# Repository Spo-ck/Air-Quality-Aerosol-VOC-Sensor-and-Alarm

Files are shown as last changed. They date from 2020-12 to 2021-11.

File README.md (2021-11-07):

# Air Quality & Aerosol (VOC) Sensor and Alarm

During the COVID-19 Pandemic, monitoring the Air Quality is important. Because of this, I developed this compact Air Quality Monitor based on the M5StickC Microcontroller and the SGP30 Sensor. The System is very small and can also be worn as a smart watch. When the eCO2  hits the threshold of 1000 ppm or the TVOC hit the threshold of 150 ppb, the sensor will trigger an alarm (sound and lght), so that you can leave a dangerous and potentially infectious room or open the windows.

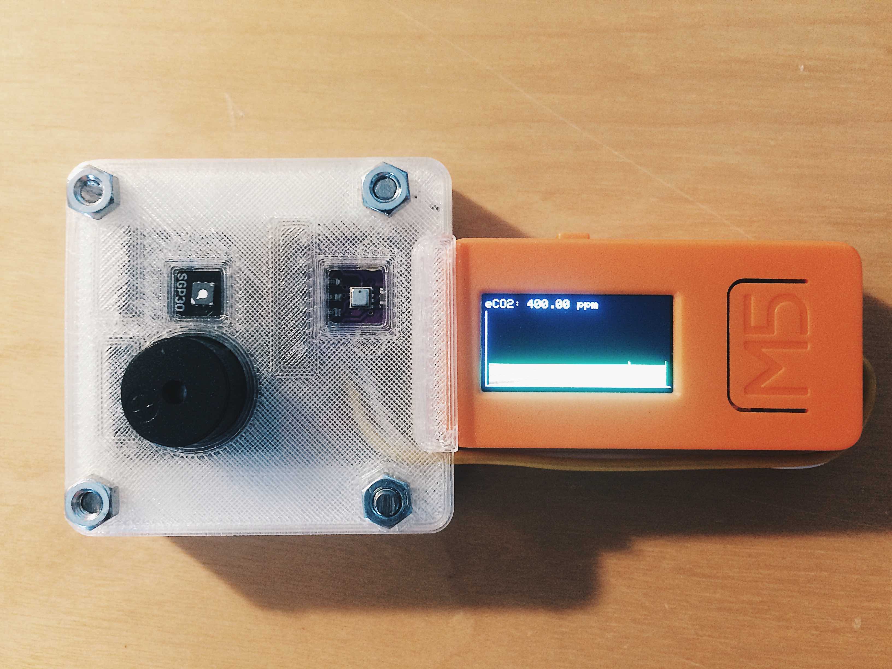
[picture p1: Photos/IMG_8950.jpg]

***System Chart View***

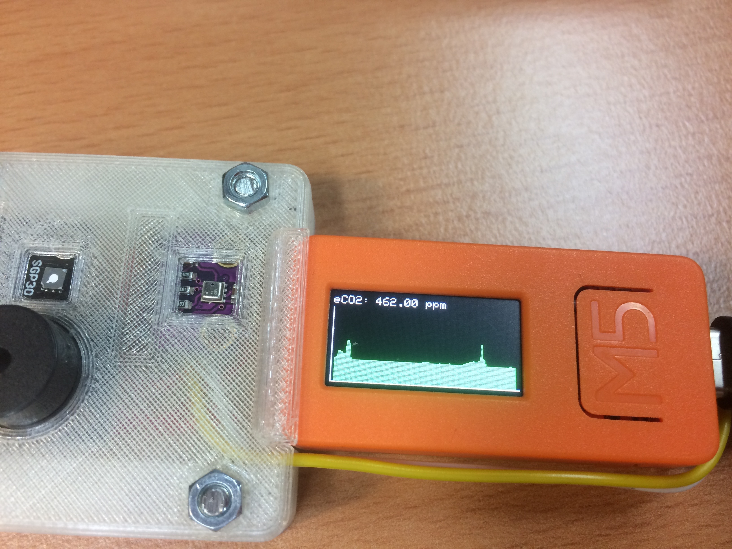
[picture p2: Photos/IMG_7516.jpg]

***System Chart View***

## Electronic

### Part List

#### Electronic
* [Buzzer module](https://www.makershop.de/module/audio/passiver-buzzer-summer/)
* [BME280 Barometric Sensor](https://www.makershop.de/sensoren/temperatur/bme280/)
* [GY-SGP30 Gas Sensor (alternative Grove SGP30)](https://www.ebay.de/itm/GY-SGP30-Air-Quality-Sensor-Breakout-VOC-and-eCO2-QITA/353147995118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)
* [M5StickC Microcontroller](https://eckstein-shop.de/M5Stack-M5StickC-PLUS-ESP32-PICO-Mini-IoT-Development-Kit)
* [Grove Sensor Cable](https://eckstein-shop.de/M5Stack-Buckled-Grove-Cable-20cm-5pcs)
* [PCB](https://www.reichelt.de/punkt-streifenrasterplati-hartpapier-160x100mm-h25ps160-p23953.html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)
* [Generic 1x8 Pin Header 2,54mm](https://www.conrad.de/de/p/wws-40-g-sl40g1-pin-header-1x40-rm2-54-straight-au-inhalt-20-stueck-800166396.html)
* Generic solid core wires (PCB)
* Generic Lead Solder

#### Tools
* [Soldering Station](https://www.conrad.de/de/p/basetech-zd-931-loetstation-digital-48-w-150-bis-450-c-1460697.html)
* [Solder Pump](https://www.conrad.de/de/p/toolcraft-lee-192-entloetsaugpumpe-antistatisch-2196503.html)
* [Third Hand](https://www.conrad.de/de/p/inline-dritte-hand-mit-lupe-800404647.html)
* [Soldering Tools](https://www.conrad.de/de/p/toolcraft-lns-151-platinenbesteck-6teilig-2182257.html)

### Pin Mapping
* GND:  Buzzer Module -, BME280 GND, SGP30 GND
* 3.3V: Buzzer Module +, BME280 VIN, SGP30 VIN
* G26:  Buzzer Module S
* G32:  BME280 SDA, SGP30 SDA
* G33:  BME280 SCL, SGP30 SCL

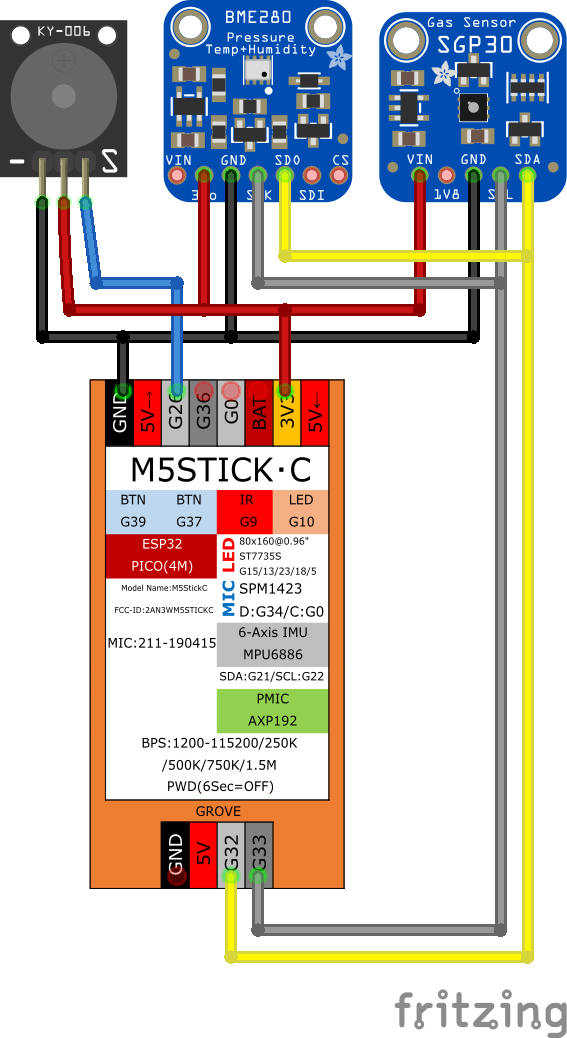
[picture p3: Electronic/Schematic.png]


***Electronic Schematic***

### Assembly

The system basically consists out of the M5StickC Microcontroller, a Buzzer Module, a BME280 Barometric Sensor Module (Temperature, Humidity, Pressure) and an SGP30 Gas Sensor Module (eCO2, TVOC, Ethanol, H2). The Buzzer Module is connected to the M5StickCs Pin Header, and the seonsors are connected to the I2C bus via the Grove connector.
All 3 components are soldered together on a single prototyping PCB. To this prototyping PCB is then soldered a 1x8 Pin Header (2.54mm) so that the PCB can be connected to the front pin header of the M5StickC. As power supply off all 3 modules, the 3.3V and the GND Pin of the M5StickCs Pin Header are utilized. The Buzzer-Modules signal pin is soldered to Pin 26, because this pin allows output signals. 
Because of the sensor modules need to be connected to the I2C Bus, which is only available on the Grove connector of the M5StickC, a 20cm Grove sensor cable was utilized. One connector was cutted of, and the 5V and GND Cables were removed. The remaining Yeallow (G32, SDA) and white (G33, SCL) cables were soldered to the corresponding pins on the PCD, to connect them to the sensor module

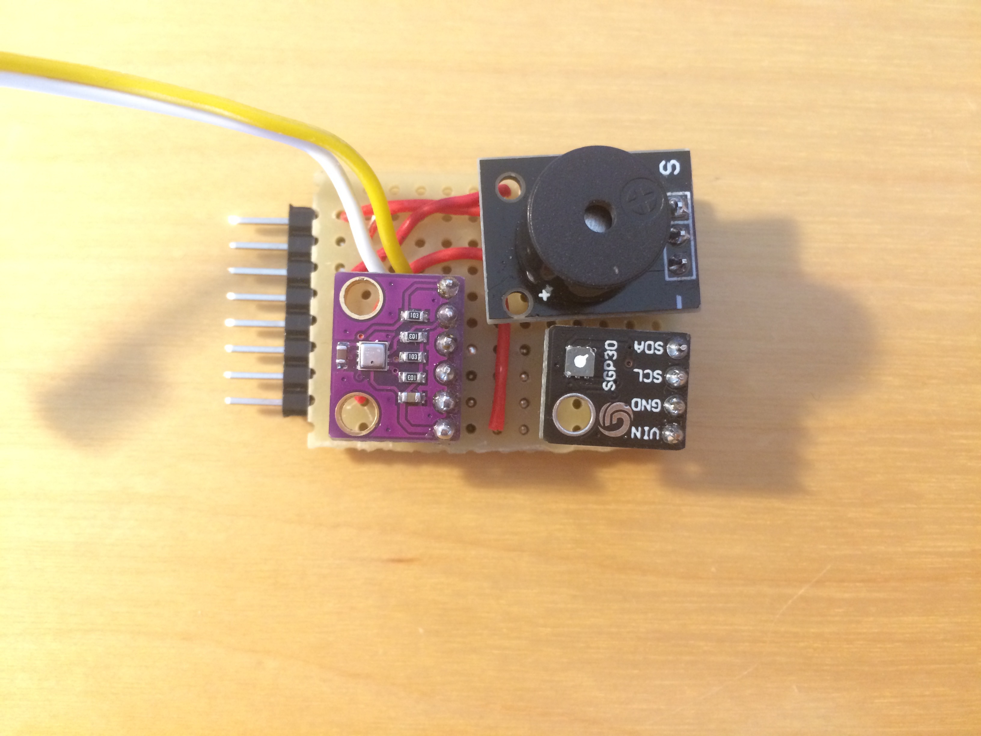
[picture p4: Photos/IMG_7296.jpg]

***PCB Front***

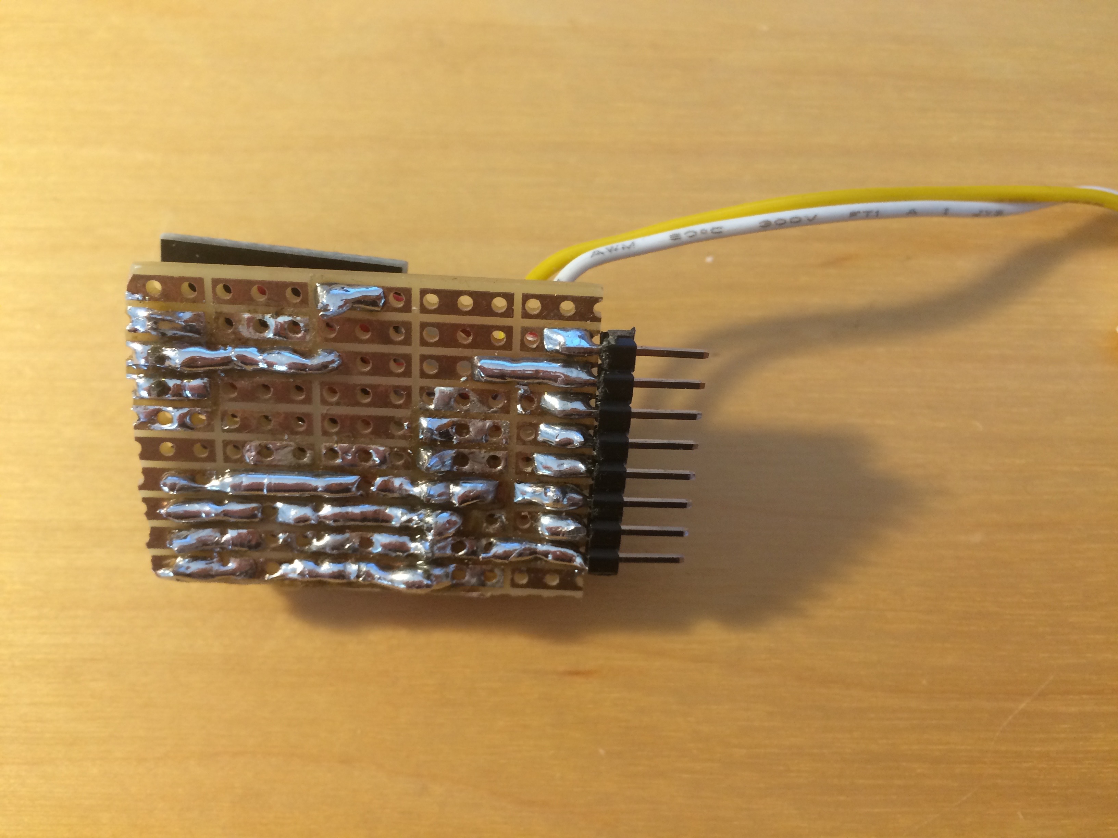
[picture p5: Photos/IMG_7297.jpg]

***PCB Back***

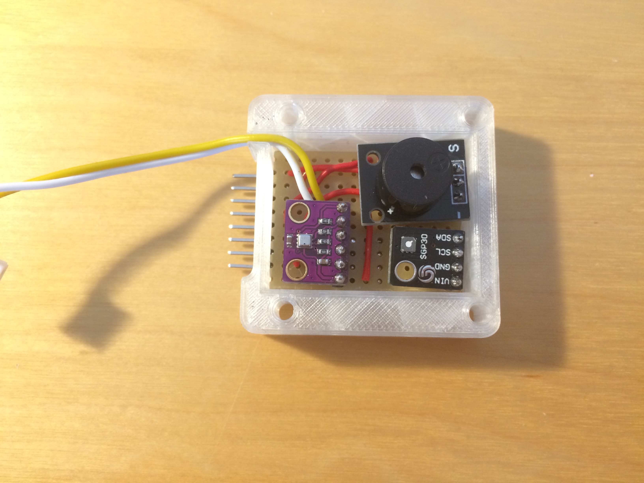
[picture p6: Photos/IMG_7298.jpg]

***PCB Cased***

## 3D-Printing

### Settings

* Profile:  0.2mm
* Infill:   10%
* Support:  Yes

### Parts
* Filament: PLA ([OWL-Filament](https://owl-filament.de))
* Printer:  Creality Ender 3
* Generic M3 Screws

### Assembly

The Sensor PCB Case consists out of 3 parts, a body frame, a front and a bottom part. For the Assembly, the Soldered PCB is first fittet into the Body Frame from the bottom so that the case mathes the pin header exactly. The Sensor cable is the placed into the small hole on the top side of the frame. After that, the Front and Bottom Party are crewed to the case. The Screwd sensor case it then first plugged into the Pin Header of the M5StickC. After that, the Sensor Cable is plugged into the Grove Connecter.


***PCB Cased***

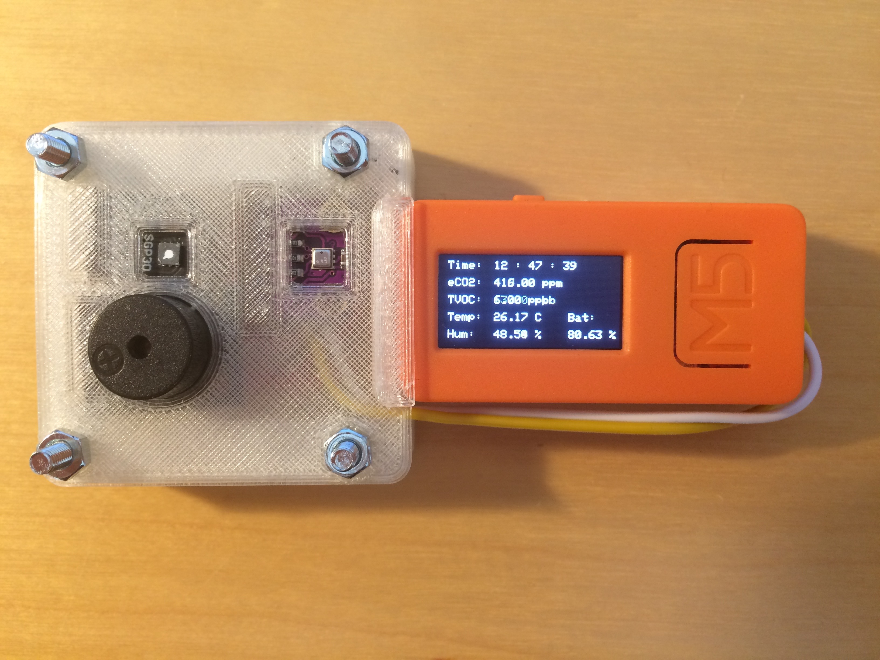
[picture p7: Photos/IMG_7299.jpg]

***System Detailed View***

## Arduino Code

### Libraries

* [M5StickC](https://github.com/m5stack/M5StickC)
* Wire.h
* [Adafruit_Sensor.h](https://github.com/adafruit/Adafruit_Sensor)
* [Adafruit_SGP30.h](https://github.com/adafruit/Adafruit_SGP30)
* [Adafruit_BME280.h](https://github.com/adafruit/Adafruit_BME280_Library)
* EEPROM.h

### About the Code

M5STcikC

The purpose of this Microcontroller Code is to generate sensor data from the sensors connected to trigger an Alarm when the Air Quality is bad. For this reason, the SGP30 Sensor Module measures eCO2 and TVOC in the breathing Air. The BME280 Barometric Sensor is required to calibrate the SGP30, and therefore to enhance its accuracy.
When the eCO2 value is over 1000 ppm, or the TVOC value is over 150 ppb, an alarm is triggered. The alarm will result in an alarm sound provided by the buzzer modele, the built in LED enlight in RED and the display turning RED. By the built in settings options, the Buzzer can also set into silent mode, where only the LED and the Display are tiggered in case of an alarm. The alarm sound is only triggered once in 60s, when the eCO2 or TVOC value hits the threshold value, but the LED will be enlighted in RED untill the Sensor Value is below the threshold again. In addition, the buzzer then disabled for 1 minute. Because of this, you will not hear multible buzzer alarms, when the sensor value is falling below, and hitting the threshold again within one minute.

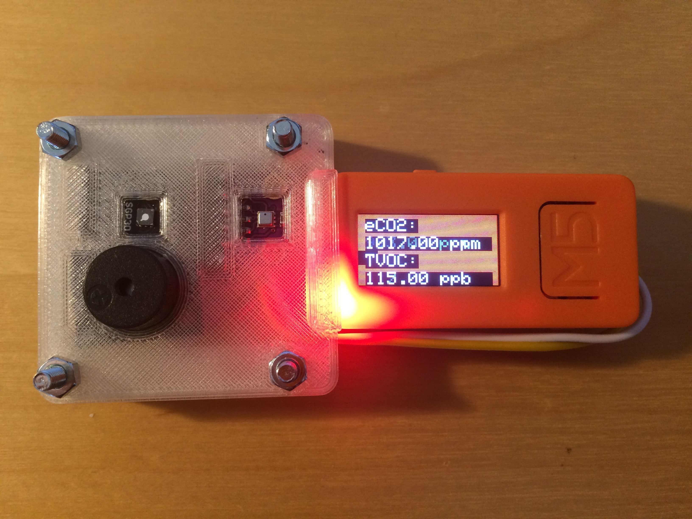
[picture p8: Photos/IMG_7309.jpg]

***System Alarm***

The System has three built in views. The Detailed View shows only the eCO2 and the TVOC values, whereas the Air Quality view shows the Time, Temperature, Humidity and the Battery Status in addition. More advanced is the Chart View, which shows the eCO2 value for the last 20min. If the critical threshold was hit, the bar shown will turn red, and if the value is below, the bar will be green. 
To navigate through the different views, the front button (Button A) is used. The last view is also stored in EEPROM, so that the sensor will start in the last used view when it starts next time.


***System Detailed View***

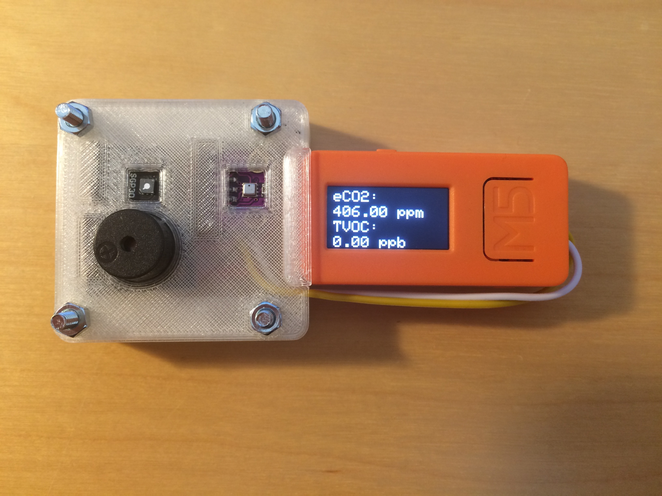
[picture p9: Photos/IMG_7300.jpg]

***System Air Quality View***

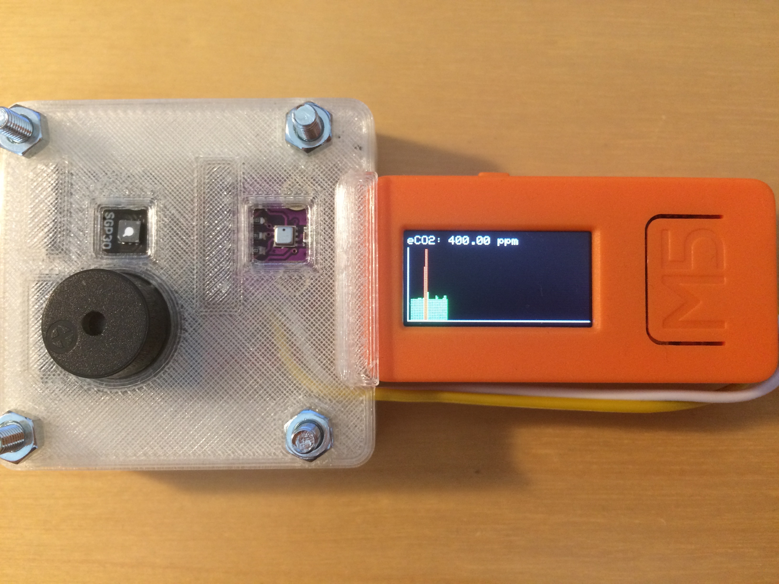
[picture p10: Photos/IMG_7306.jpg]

***System Chart View***

Nomally, the display is On all time, but it is also possible to disable the display. In this mode, the front button needs to be pressed one time to turn the display on for 5s. After that, pressing this button again will make the view change as usual.

In addidion, a settings view is implemented. In the settings view, one can change the Display Mode (Display always on or on for 5s) and the Alarm Mode (Buzzer turned off or on). This view is opened when the side button (Button B) is pressed. In this view, the first option it the Display Mode. When the Front Button is pressed, the Mode will change (Display always on or on for 5s). The option is confirmed with pressind the side button again. After that, the settings for the Alarm Mode (Buzzer turned off or on) is opened and can be changed with pressing the front button. In general, the active settings option is indicated with a red line on the left side. Pressing the side button a third time will confirm the settings, and open the last Sensor View again.

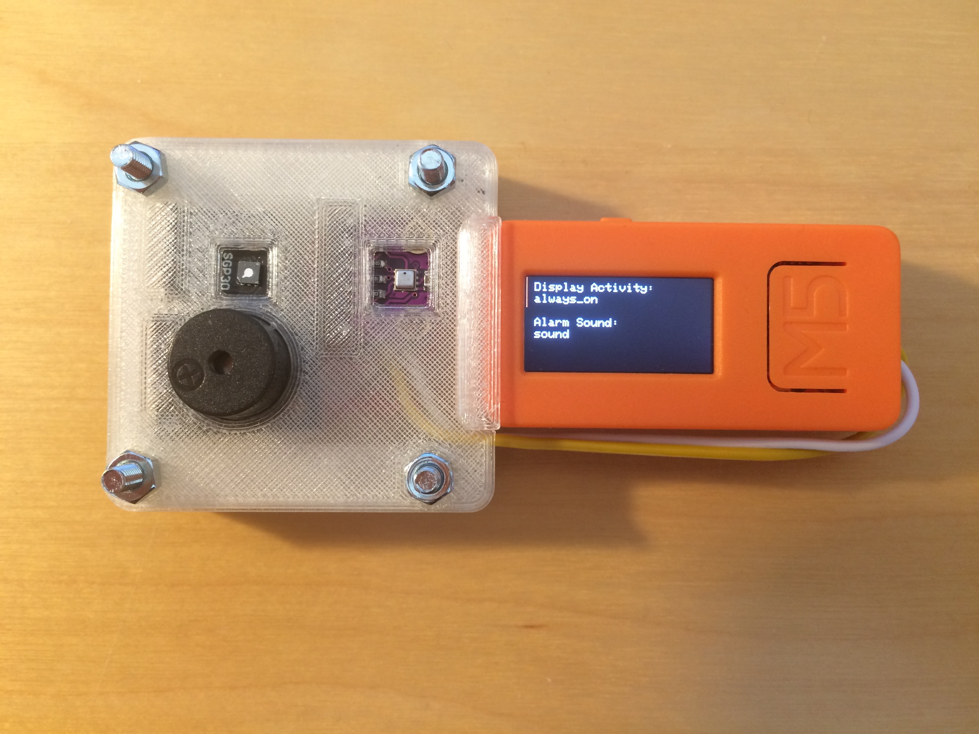
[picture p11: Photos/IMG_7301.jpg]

***System Settings***

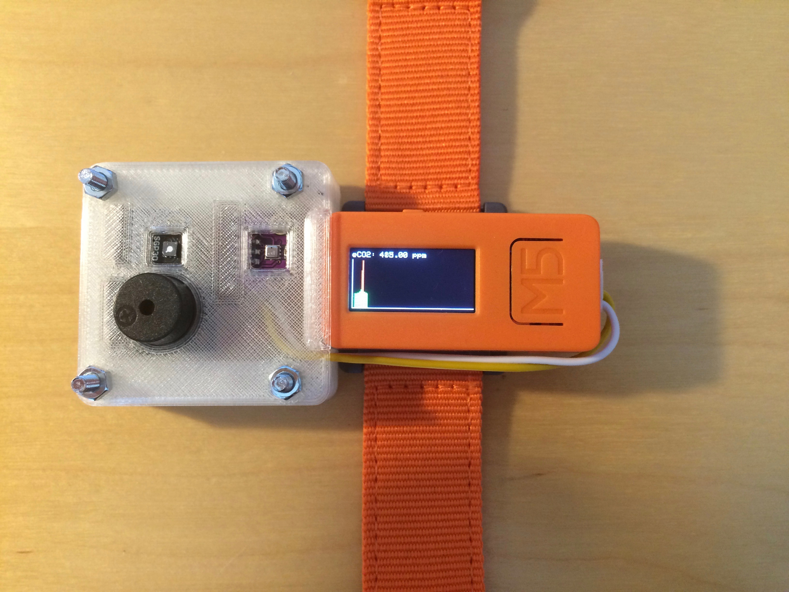
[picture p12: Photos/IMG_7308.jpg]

***System as Smart Watch close up***

### How To

In order to flash this code on the M5StickC, the Arduino IDE needs to download and to be installed first. Then, the M5StickCs driver and the above mentioned libraries need to be installed. You can then open (or copy/past) the code into the IDE and flash it.

* [M5StickC Manual and Software](https://m5stack.com/pages/download)
* [Arduino IDE](https://www.arduino.cc/en/software)

## Limit Values

In my design I used the value of 1000 ppm eCO2 and 150 ppb TVOC as limits for an alarm of the Sensor System. These limits mark the boundary condition for unobjectionable indoorair, between 1000 ppm and 2000ppm CO2 and between 150 ppb and 1300 ppb TVOC the airquality is questionable. Above these limits the Airquality is not directly infectious, but hygienically inacceptable. I got these values from the following sources:

* [Umweltbundesamt CO2 Grenzwerte in Innenräumen](https://www.umweltbundesamt.de/sites/default/files/medien/pdfs/kohlendioxid_2008.pdf)
* [Air-Q TVOC Limits](https://www.air-q.com/messwerte/voc)

## Datasheets

* [Sensurion SGP30 Gas Sensor](https://www.sensirion.com/fileadmin/user_upload/customers/sensirion/Dokumente/9_Gas_Sensors/Datasheets/Sensirion_Gas_Sensors_Datasheet_SGP30.pdf)
* [Bosh Sensortech BME280 Barometric Sensor](https://www.bosch-sensortec.com/media/boschsensortec/downloads/datasheets/bst-bme280-ds002.pdf)

## Hot Sensors

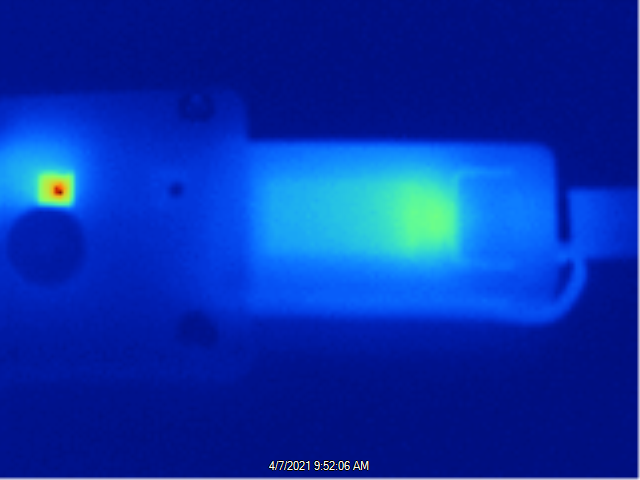
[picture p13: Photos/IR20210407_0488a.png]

***Thermal Scan***

Some users reported their SGP30 Sensor Boards where heating up, but during my testruns, I was not able to feel the heat. To clearify the issue, I did a thermal scan of my Sensor System. In general, the SGP30 sensor uses hot plates to measure TVOC and CO2 equivalents. Because of this, the Sensor gets hot in its centre spot, and also heats up its case. In my thermal scan, the sensors case (green) heated up to 43°C, and the central hot plate (red) heated up to 52°C. Since my sensor did not consume more current during my testruns then expected, since it was perfectly working with four sensor readings per second and because I was not able to sense this heat with my finger on the sensor, I would say it is save to use the sensor and reasonable that its getting hot.

## Still to be implemented

Every Gas Sensor is different, so it also needs to be calibrated. In order to calibrate it, it needs to be turned on for 12h, and this value is then valid for 7 days. To do so, the value needs to be stored in EEPROM, and send to the sensor in the Settings function. Because I never used it for 12h, this is not implemented yet. If not set, the sensor used 400 ppm for eCO2 and 0 ppb for TVOC as calibration value.
Also, it was not possible to set the display off completely. In the current implementation, it will only be black in the 5s-On mode and not completely off.

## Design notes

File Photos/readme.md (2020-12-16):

# Photos


***PCB Front***


***PCB Back***


***PCB Cased***


***System Detailed View***


***System Air Quality View***


***System Chart View***

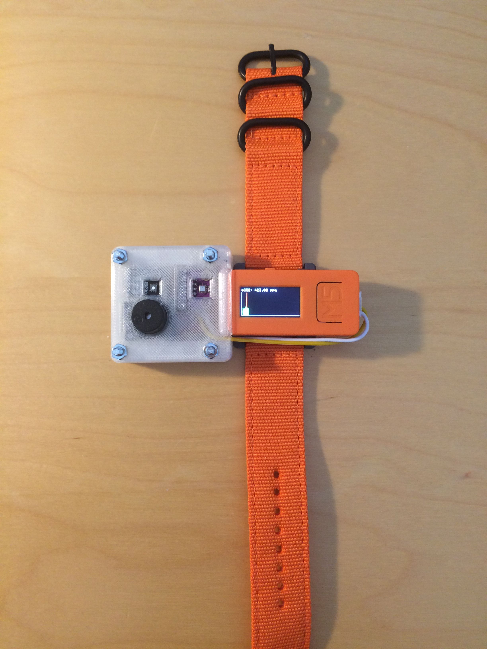
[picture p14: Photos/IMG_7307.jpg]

***System as Smart Watch***


***System as Smart Watch close up***


***System Alarm***


***System Settings***

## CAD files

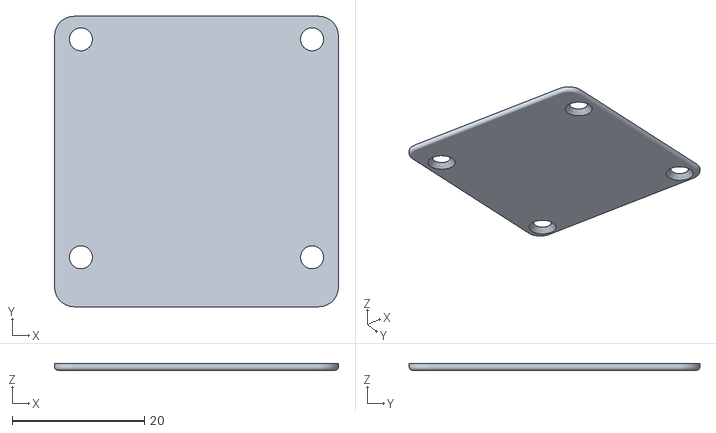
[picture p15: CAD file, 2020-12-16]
3d-Printing/AirQualitySensor07_bottom_plate.stl
43.0 x 44.0 x 1.00

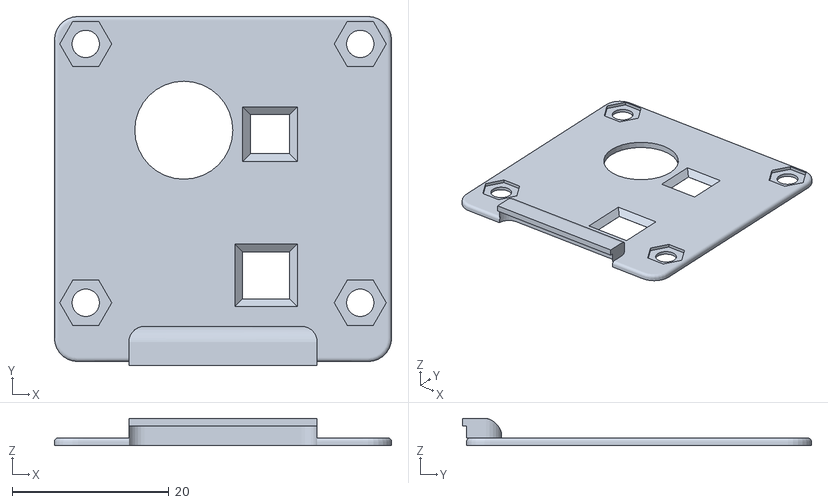
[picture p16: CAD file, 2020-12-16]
3d-Printing/AirQualitySensor08_top_plate.stl
43.0 x 44.5 x 3.50

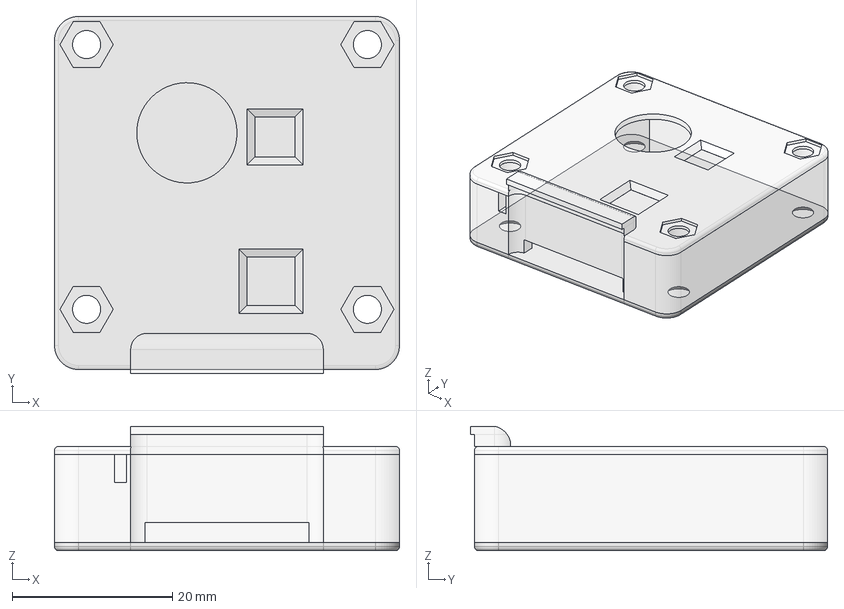
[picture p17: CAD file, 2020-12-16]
3d-Printing/AirQualitySensor08.FCStd
43.0 x 44.5 x 15.5 mm
Top Plate
BottomPlate

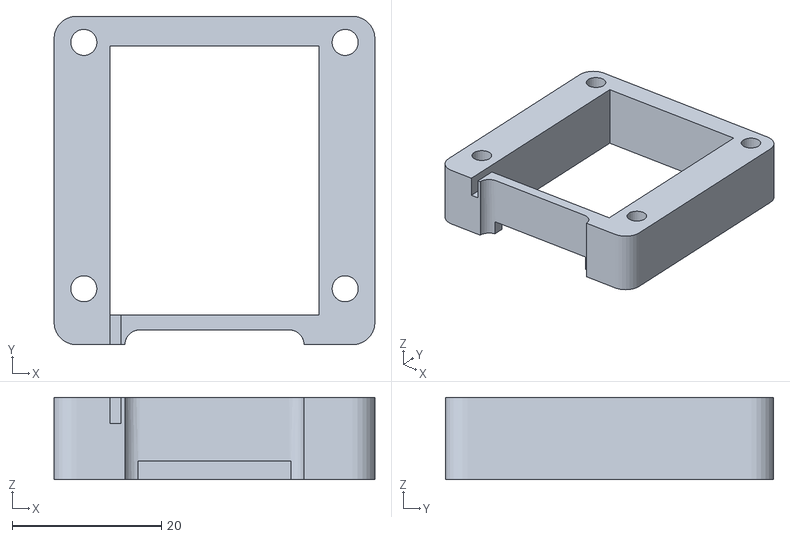
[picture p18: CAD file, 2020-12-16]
3d-Printing/AirQualitySensor08_body.stl
43.0 x 44.0 x 11.0

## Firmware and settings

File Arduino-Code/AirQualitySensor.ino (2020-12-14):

#include <M5StickC.h>
#include <Wire.h>
#include <Adafruit_Sensor.h>
#include "Adafruit_SGP30.h"
#include <Adafruit_BME280.h>
#include <EEPROM.h>

// EEPORM
#define EEPROM_size       1
const int Mode_Register       = 0;
const int Activity_Register       = 1;
const int Sound_Register       = 2;

// Modes
#define serial_mode false // if false, no telemetry will be displayed on serial

// Sensors
// Sensor Objects
Adafruit_SGP30    sgp;
Adafruit_BME280   bme;
// Variables
float tvoc              = 0;
float eco2              = 0;
float raw_H2            = 0;
float raw_ethanol       = 0;
float temp              = 0;
float pressure          = 0;
float humidity          = 0;

// Memory
#define num_history 150
int   eco2_history[num_history];
int   history_postion   = 0;
int   history_mean      = 0;
int   history_mean_num  = 0;
unsigned long  history_mean_time    = 10000;  // Time that is used to calculate the mean over for 1 data point
unsigned long  history_mean_millis  = 0;

// Buzzer
int freq                = 2000;
int channel             = 0;
int resolution          = 8;
int buzzer_pin          = 26;

// LED
int LED_r               = 10;
bool LED_State          = false;

// Alarm
bool ALARM              = false;
long last_ALARM         = -60000;
int eCO2_Threshold      = 1000; // ppm
int tvoc_Threshold      = 150;  // ppb
String alarm_mode       = "sound";

// Display
String display_mode           = "diagram";
String display_mode_last      = "diagram";
String display_activity       = "5s_on";
String display_activity_last  = display_activity;
int    display_activity_time  = -1;
uint8_t display_brightness    = 255;

// Buttons
const int Button_A      = 37;
const int Button_B      = 39;

// RTC
// Struct
RTC_TimeTypeDef RTC_TimeStruct;
RTC_DateTypeDef RTC_DateStruct;
// Variables
int time_hh = RTC_TimeStruct.Hours;
int time_mm = RTC_TimeStruct.Minutes;
int time_ss = RTC_TimeStruct.Seconds;
unsigned long time_millis = 0;
unsigned long  loop_interval = 250;

///////////////////////////////////////////////////
void setup() {
    
  // Init Libraries
  Serial.begin(115200);
  m5.begin();
  Wire.begin();
  Serial.println();
  
  // EEPROM
  // Initialise EEEPROM
  EEPROM.begin(EEPROM_size);
//  // Flash EEPROM
//  EEPROM.write(Mode_Register, 0); // Write 0 to register 0
//  EEPROM.commit();
//  
//  EEPROM.write(Activity_Register, 0); // Write 0 to register 0
//  EEPROM.commit();
//  
//  EEPROM.write(Sound_Register, 1); // Write 0 to register 0
//  EEPROM.commit();
  // Read Out Mode From EEPROM and Change Mode
  int last_mode = EEPROM.read(Mode_Register);
  if (last_mode == 0){    
    display_mode = "air_quality";  
  }
  else  if (last_mode == 1){
    display_mode = "all_readings";
  }
  else  if (last_mode == 2){
    display_mode = "diagram";
  }
  display_mode_last = display_mode;

  last_mode = EEPROM.read(Activity_Register);
  if (last_mode == 0){    
    display_activity = "always_on";
  }
  else  if (last_mode == 5){
    display_activity = "5s_on";
  }
  display_activity_last = display_activity;

  last_mode = EEPROM.read(Sound_Register);
  if (last_mode == 0){    
    alarm_mode == "silent";
  }
  else  if (last_mode == 1){
    alarm_mode == "sound";
  }
  
  // Init Display
  M5.Lcd.setRotation(1);
  M5.Lcd.fillScreen(BLUE);
//  M5.Lcd.setBrightness(display_brightness); // Doesn't work with the Library
  
  // Init Sensors
  // SGP30
  if (! sgp.begin()) {
    if (serial_mode) {
      Serial.println("SGP30 not found");
      
      M5.Lcd.setTextColor(TFT_WHITE);
      M5.Lcd.setTextSize(2);
      M5.Lcd.setCursor(10, 5);
      M5.Lcd.print("Can't find Air Quality Sensor ");
    
    }
  }
  else {
    if (serial_mode) {
      Serial.println("SGP30 found");

      Serial.print("Found SGP30 serial #");
      Serial.print(sgp.serialnumber[0], HEX);
      Serial.print(sgp.serialnumber[1], HEX);
      Serial.println(sgp.serialnumber[2], HEX);
    }
    
    // Warm Sensor Up
    sgp.IAQmeasure();
    
    float last_eco2 = sgp.eCO2;
    float last_TVOC = sgp.TVOC;
  
    if (serial_mode) {
      Serial.println("Warming Up SGP30 Sensor");
    }
    
    sgp.IAQmeasure();

    M5.Lcd.setTextColor(TFT_WHITE);
    M5.Lcd.setTextSize(2);
    M5.Lcd.setCursor(10, 5);
    M5.Lcd.print("Warming Up");
    M5.Lcd.setCursor(10, 25);
    M5.Lcd.print("Air Quality");
    M5.Lcd.setCursor(10, 45);
    M5.Lcd.print("Sensor ");
    M5.Lcd.setCursor(10, 65);
    
    while (last_eco2 == float(sgp.eCO2) && last_TVOC == sgp.TVOC) {
      sgp.IAQmeasure();

      if (serial_mode) {
        Serial.println("Warming Up SGP: eCO2 " + String(sgp.eCO2) + " ppm" + " TVOC " + String(sgp.TVOC) + " ppb");
      }
     }
  } 
  M5.Lcd.fillScreen(TFT_BLACK);
  
  // BME280
  if (! bme.begin(0x76, &Wire)) {
    if (serial_mode) {
      Serial.println("BMP280 not found");
    }
  }
  else {
    if (serial_mode) {
      Serial.println("BMP280 found");
        
      Serial.print("Temperature " + String(bme.readTemperature()) + "°C\t");
      Serial.print("Pressure " + String(bme.readPressure()) + " Bar\t");
      Serial.println("Humidity" + String(bme.readHumidity()) + "%");
    }
  }

  // FIl History
  for (int i = 0; i < 150; i++) {
    eco2_history[i] = -1;// default value
  }
  
  // Buzzer
  // buzzer
  ledcSetup(channel, freq, resolution);
  ledcAttachPin(buzzer_pin, channel);
  ledcWrite(channel, 0);
  
  // LED
  // ROT, built in
  pinMode (LED_r, OUTPUT);
  digitalWrite(LED_r, HIGH);

  // Button
  pinMode(Button_A, INPUT_PULLUP);
  pinMode(Button_B, INPUT_PULLUP);
  attachInterrupt(digitalPinToInterrupt(Button_A), Function_Button_A, HIGH);
  attachInterrupt(digitalPinToInterrupt(Button_B), Function_Button_B, HIGH);

  // RTC
  // Generate Struct
  RTC_TimeTypeDef TimeStruct;
  RTC_DateTypeDef DateStruct;

  TimeStruct.Hours    = 19;
  TimeStruct.Minutes  = 47;
  TimeStruct.Seconds  = 00;
  DateStruct.WeekDay  = 4;
  DateStruct.Date     = 10;
  DateStruct.Month    = 12;
  DateStruct.Year     = 2020;
  
//  // Set Time and Date
//  M5.Rtc.SetTime(&TimeStruct);
//  M5.Rtc.SetData(&DateStruct);

  // Get Time from RTC
  M5.Rtc.GetTime(&RTC_TimeStruct);
  time_hh     = RTC_TimeStruct.Hours;
  time_mm     = RTC_TimeStruct.Minutes;
  time_ss     = RTC_TimeStruct.Seconds;
}


////////////////////////
// Measurement
////////////////////////

void ALARM_LED(String State) {
  if (State == "Activate") {
    digitalWrite(LED_r, LOW);
    LED_State = true;
  }
  else if (State == "Deactivate") {
    digitalWrite(LED_r, HIGH);
    LED_State = false;
  }
  else if (State == "Change") {
    if (LED_State == false){
      digitalWrite(LED_r, LOW);
      LED_State = true;
    }
    else {
      digitalWrite(LED_r, HIGH);
      LED_State = false;
    }
  }
}

void ALARM_Buzzer() {
  
  M5.Lcd.fillScreen(RED);
  
  // Play Buzzer Pattern
  ledcWrite(channel, 100);  // Buzzer On
  wait_for(500);            // Wait 500ms
  ledcWrite(channel, 0);    // Buzzer Off
  wait_for(500);            // Wait 500ms
  ledcWrite(channel, 100);  // Buzzer On
  wait_for(500);            // Wait 500ms
  ledcWrite(channel, 0);    // Buzzer Off
  wait_for(500);            // Wait 500ms
  ledcWrite(channel, 100);  // Buzzer On
  wait_for(750);            // Wait 750ms
  ledcWrite(channel, 0);    // Buzzer Off

  M5.Lcd.fillScreen(TFT_BLACK);
}

void wait_for(int milliseconds){
  unsigned long alarm_time = millis();
  
  while(millis() - alarm_time < milliseconds){
    // Measurement
    sensor_readings();
    store_history();    // Save Readings in History
    display_readings();
  }
}

////////////////////////
// Measurement
////////////////////////
void sensor_readings() {
  // Measure
  // Sensor Reading
  if (! sgp.IAQmeasure()) {
    Serial.println("Measurement failed");
    return;
  }
  else {
    // BME280
    temp        = bme.readTemperature();
    pressure    = bme.readPressure();
    humidity    = bme.readHumidity();

    // SGP30
    sgp.setHumidity(getAbsoluteHumidity(temp, humidity));

    sgp.IAQmeasure();
    tvoc        = sgp.TVOC;
    eco2        = sgp.eCO2;

    sgp.IAQmeasureRaw();
    raw_H2      = sgp.rawH2;
    raw_ethanol = sgp.rawEthanol;
  }
}

uint32_t getAbsoluteHumidity(float temperature, float humidity) {
  // approximation formula from Sensirion SGP30 Driver Integration chapter 3.15
  const float absoluteHumidity = 216.7f * ((humidity / 100.0f) * 6.112f * exp((17.62f * temperature) / (243.12f + temperature)) / (273.15f + temperature)); // [g/m^3]
  const uint32_t absoluteHumidityScaled = static_cast<uint32_t>(1000.0f * absoluteHumidity); // [mg/m^3]
  return absoluteHumidityScaled;
}

void store_history() {


  if (history_mean_num  == 0) {
    history_mean_millis = millis();
  }

  if (history_mean_time > (millis() - history_mean_millis)) {
    
    if (history_mean_num == 0) {
       history_mean = eco2;
    }
    else {
      // Calculate Mean
      history_mean = history_mean * history_mean_num;
      history_mean = history_mean + eco2;
    }

    history_mean_num++;
    history_mean = history_mean / history_mean_num;
  }
  else {
    // Save History
    eco2_history[history_postion] = int(history_mean);
    
    history_mean_num = 0;
    
    history_postion++;

    eco2_history[history_postion] = -1;
    
    if (history_postion >= num_history) {
      history_postion = 0;
    } 
  }
}


////////////////////////
// Buttons
////////////////////////
void Function_Button_A() {

  if (display_activity != "always_on" && display_activity_time == -1) {
    // if the display is not always on, the time when the putton is pressed needs to be stored
    display_activity_time = millis();
 //   M5.Lcd.setBrightness(display_brightness); ; // Doesn't work with the Library
  }
  else if (display_activity != "always_on" && display_activity_time != -1) {
    change_mode();
  }
  else {
    change_mode();
  }
  

//  // Activate new Mode
//  display_readings();
// This line was written to update the display right after clicking, now it will just take some milliseconds to update the display<.
// otherwise it is likely, that the history array is open for writing at the same time when the interrupt comes
// in this case, the array will be read out, which is not possible when the controller is in writing mode,
// what would then trigger a reboot
}

void Function_Button_B() {
  M5.Lcd.fillScreen(TFT_BLACK);
  
  display_activity_last = display_activity;
  display_activity = "always_on";
  
  display_mode = "settings";

  detachInterrupt(digitalPinToInterrupt(Button_A));
  detachInterrupt(digitalPinToInterrupt(Button_B));
  attachInterrupt(digitalPinToInterrupt(Button_A), Function_Button_A1, HIGH);
  attachInterrupt(digitalPinToInterrupt(Button_B), Function_Button_B1, HIGH);

  M5.Lcd.drawLine(3, 0, 3, 25, RED);
}


void Function_Button_A1() {
  if (display_activity_last == "always_on") {
    display_activity_last = "5s_on";
  }
  else if (display_activity_last == "5s_on") {
    display_activity_last = "always_on";
  }
}

void Function_Button_B1() {
  detachInterrupt(digitalPinToInterrupt(Button_A));
  detachInterrupt(digitalPinToInterrupt(Button_B));
  pinMode(Button_A, INPUT_PULLUP);
  pinMode(Button_B, INPUT_PULLUP);
  attachInterrupt(digitalPinToInterrupt(Button_A), Function_Button_A2, HIGH);
  attachInterrupt(digitalPinToInterrupt(Button_B), Function_Button_B2, HIGH);

  M5.Lcd.drawLine(3, 0, 3, 25, TFT_BLACK);
  M5.Lcd.drawLine(3, 33, 3, 55, RED);
}


void Function_Button_A2() {
  
  if (alarm_mode == "sound") {
    alarm_mode = "silent";
  }
  else if (alarm_mode = "silent") {
    alarm_mode = "sound";
  }
}

void Function_Button_B2() {
  display_mode = display_mode_last;
  display_activity = display_activity_last;

  M5.Lcd.fillScreen(TFT_BLACK);
    
  detachInterrupt(digitalPinToInterrupt(Button_A));
  detachInterrupt(digitalPinToInterrupt(Button_B));
  pinMode(Button_A, INPUT_PULLUP);
  pinMode(Button_B, INPUT_PULLUP);
  attachInterrupt(digitalPinToInterrupt(Button_A), Function_Button_A, HIGH);
  attachInterrupt(digitalPinToInterrupt(Button_B), Function_Button_B, HIGH);
}

void change_mode() {
  M5.Lcd.fillScreen(TFT_BLACK);
  
  // Choose new Display Mode
  if (display_mode == "air_quality"){
    display_mode = "all_readings";
  }
  else if (display_mode == "all_readings"){
    display_mode = "diagram";
  }
  else if (display_mode == "diagram"){
    display_mode = "air_quality";    
  }
}


void Save_Mode_To_EEPROM() {
  if (display_mode == "air_quality"){
    EEPROM.write(Mode_Register, 0); // Write 1 to register 0
    EEPROM.commit();
  }
  else if (display_mode == "all_readings"){
    EEPROM.write(Mode_Register, 1); // Write 2 to register 0
    EEPROM.commit();
  }
  else if (display_mode == "diagram"){   
    EEPROM.write(Mode_Register, 2); // Write 0 to register 0
    EEPROM.commit();
  }

  display_mode_last = display_mode;
}

////////////////////////
// Communication
////////////////////////
void display_readings(){
  
  if (display_mode == "air_quality"){
    M5.Lcd.setTextColor(TFT_WHITE, TFT_BLACK);
    M5.Lcd.setTextSize(2);
    
    M5.Lcd.setCursor(10, 5);
    M5.Lcd.print("eCO2:");
    M5.Lcd.setCursor(10, 25);
    M5.Lcd.print(eco2);
    M5.Lcd.println(" ppm   ");
  
    M5.Lcd.setCursor(10, 45);
    M5.Lcd.print("TVOC:");
    M5.Lcd.setCursor(10, 65);
    M5.Lcd.print(tvoc);
    M5.Lcd.println(" ppb   ");
  }
  else if (display_mode == "all_readings"){

    // Get Time from RTC
    M5.Rtc.GetTime(&RTC_TimeStruct);
    time_hh     = RTC_TimeStruct.Hours;
    time_mm     = RTC_TimeStruct.Minutes;
    time_ss     = RTC_TimeStruct.Seconds;
  
    M5.Lcd.setTextColor(TFT_WHITE, TFT_BLACK);
    M5.Lcd.setTextSize(1);

    M5.Lcd.setCursor(10, 5);
    M5.Lcd.print("Time: ");
    M5.Lcd.setCursor(50, 5);
    M5.Lcd.print(time_hh);
    M5.Lcd.print(" : ");
    M5.Lcd.print(time_mm);
    M5.Lcd.print(" : ");
    M5.Lcd.print(time_ss);
  
    M5.Lcd.setCursor(10, 20);
    M5.Lcd.print("eCO2: ");
    M5.Lcd.setCursor(50, 20);
    M5.Lcd.print(eco2);
    M5.Lcd.println(" ppm   ");
  
    M5.Lcd.setCursor(10, 35);
    M5.Lcd.print("TVOC: ");
    M5.Lcd.setCursor(50, 35);
    M5.Lcd.print(tvoc);
    M5.Lcd.println(" ppb   ");
    
    M5.Lcd.setCursor(10, 50);
    M5.Lcd.print("Temp: ");
    M5.Lcd.setCursor(50, 50);
    M5.Lcd.print(temp);
    M5.Lcd.println(" C   ");

    M5.Lcd.setCursor(10, 65);
    M5.Lcd.print("Hum: ");
    M5.Lcd.setCursor(50, 65);
    M5.Lcd.print(humidity);
    M5.Lcd.println(" %   ");

    M5.Lcd.setCursor(115, 50);
    M5.Lcd.print("Bat: ");
    M5.Lcd.setCursor(115, 65);
    if (M5.Axp.GetWarningLevel()) {
      M5.Lcd.setTextColor(TFT_WHITE, RED);
    }
    float bat_level = ((M5.Axp.GetBatVoltage() - 3.00) / 0.9) * 100;
    if (bat_level > 100) {
      M5.Lcd.print(100);
    }
    else {      
      M5.Lcd.print(bat_level);
    }
    
    M5.Lcd.println(" %");
  }
  else if (display_mode == "diagram"){
    // Display Axis
    M5.Lcd.drawLine(5, 76, 160, 76, TFT_WHITE);  // X-Axis
    M5.Lcd.drawLine(5, 76, 5, 14, TFT_WHITE);    // Y-Axis

    // Display Text-Value
    M5.Lcd.setTextColor(TFT_WHITE, TFT_BLACK);
    M5.Lcd.setTextSize(1);
    
    M5.Lcd.setCursor(5, 4);
    M5.Lcd.print("eCO2: ");
    M5.Lcd.setCursor(40, 4);
    M5.Lcd.print(eco2);
    M5.Lcd.println(" ppm   ");
    
    // Print Bars
    int actual_pos = history_postion;

    for (int i = num_history - 1; i >= 0 ; i = i - 1) {
      // Check every time if the mode is still diagram or if this changed
      // Otherwise there will be fragments on the next visualisation page on the display
      if (display_mode == "diagram"){        
         // CHeck if there is something in the memory to display (default is -1)
         if (eco2_history[actual_pos] >= 0.00) {
            
            if (eco2_history[actual_pos] < eCO2_Threshold) {   // Values below Threshold will be green
              M5.Lcd.drawLine(i + 8, ((75 - (eco2_history[actual_pos] / (1.5 * eCO2_Threshold)) * 62) - 1), i + 8, 14, BLACK);
              M5.Lcd.drawLine(i + 8, 75, i + 8, (75 - (eco2_history[actual_pos] / (1.5 * eCO2_Threshold)) * 62), GREEN);
            }
            else if (eco2_history[actual_pos] >= eCO2_Threshold && eco2_history[actual_pos] < (1.5 * eCO2_Threshold)){   // Values above Threshold will be red
              M5.Lcd.drawLine(i + 8, ((75 - (eco2_history[actual_pos] / (1.5 * eCO2_Threshold)) * 62) - 1), i + 8, 14, BLACK);
              M5.Lcd.drawLine(i + 8, 75, i + 8, (75 - ((eco2_history[actual_pos] / (1.5 * eCO2_Threshold)) * 62)), RED);
            }
            else {  // if the value is greater 1.5*eCO2_Treshold, there will only be one red bar displayed
              M5.Lcd.drawLine(i + 8, 75, i + 8, 15, RED); 
            }
          }
          
          actual_pos++;
          
          if (actual_pos >= num_history) {
            actual_pos = 0;
          } 
      }
    }
  }
  else if (display_mode == "settings"){
    
    M5.Lcd.setTextColor(TFT_WHITE, TFT_BLACK);
    M5.Lcd.setTextSize(1);

    M5.Lcd.setCursor(10, 5);
    M5.Lcd.print("Display Activity: ");
    M5.Lcd.setCursor(10, 15);
    M5.Lcd.print(String(display_activity_last) + "     ");
  
    M5.Lcd.setCursor(10, 35);
    M5.Lcd.print("Alarm Sound:   ");
    M5.Lcd.setCursor(10, 45);
    M5.Lcd.print(String(alarm_mode) + "     ");    
  }
}

void print_readings() {
  // Print
  Serial.print("TVOC: " + String(tvoc) + " ppb\t");
  Serial.print(" | eCO2 " + String(eco2) + " ppm\t");
  Serial.print(" | Raw H2: " + String(raw_H2) + "\t");
  Serial.print(" | Raw Ethanol: " + String(raw_ethanol) + "\t");
  Serial.print(" | Temperature: " + String(temp) + "°C\t");
  Serial.print(" | Pressure: " + String(pressure) + " Bar\t");
  Serial.println(" | Humidity: " + String(humidity) + "%");
}

////////////////////////
// Main Loop
////////////////////////
void loop() {
  
  time_millis = millis();
  
  // Measurement
  sensor_readings();  // Sensor Reading
  store_history();    // Save Readings in History

  // Sensor Display
  // Serial
  if (serial_mode == true) {
    print_readings();
  }
  // Display
  if (display_activity == "always_on") {
    display_readings();
  }
  else if (display_activity == "5s_on") {
    
    if (millis() - display_activity_time < 5000 && display_activity_time != -1) {
      display_readings();
    }
    else if (millis() - display_activity_time >= 5000 && display_activity_time != -1) {
      M5.Lcd.fillScreen(TFT_BLACK);
//      M5.Lcd.setBrightness(0); ; // Doesn't work with the Library
      display_activity_time = -1;
    }    
    else if (eco2 > (eCO2_Threshold * 0.8) || tvoc > (tvoc_Threshold * 0.8)) {
      if (display_activity_time == -1) {
        display_activity_time = millis();
      }
    }
  }

  // Check for Alarms
  // Visual Alarm everytime the eCO2 is over Threshold
  // Audio Alarm one time in 60s
  if (ALARM == false) {                                   // Check if an Alarm was triggered Previously
    if (eco2 > eCO2_Threshold || tvoc > tvoc_Threshold) { // Check if measurement exceeds threshold
      ALARM = true;
      ALARM_LED("Activate");
  
      if (millis() - last_ALARM > 60000 && alarm_mode == "sound") {
        ALARM_Buzzer();
        last_ALARM = millis();
      }
    }
  }
  else if (eco2 <= eCO2_Threshold && tvoc <= tvoc_Threshold && ALARM == true) {
    ALARM_LED("Deactivate");
    
    ALARM = false;
  }
  
  // if the mode has changed for the display, store this in eeprom
  if (display_mode_last != display_mode && display_mode != "settings") {
    Save_Mode_To_EEPROM();
  }

  Serial.print(M5.Axp.GetBatVoltage());
  Serial.print(" - ");
  Serial.print(M5.Axp.GetAPSVoltage());
  Serial.print(" - ");
  Serial.println(M5.Axp.GetWarningLevel());
  
  // Just run the loop 4 times per second
  if (millis() - time_millis < loop_interval) {
//    Serial.println(millis() - time_millis);
    delay(loop_interval - (millis() - time_millis));
  }
}
